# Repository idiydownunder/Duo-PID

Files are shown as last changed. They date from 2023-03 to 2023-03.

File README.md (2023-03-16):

# Duo-PID

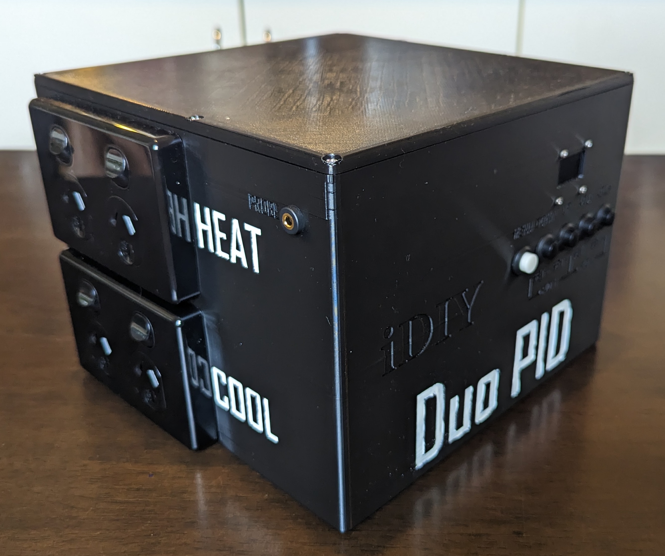
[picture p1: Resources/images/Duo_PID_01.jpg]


### Introduction

The Duo PID project is a device for controlling heating and or cooling operations with PID control. This project is split into two channels each with its own PID and temp sensor. I designed it for use with my fermentaion process when making home brew. However it could also be used for heating and cooling of spaces in the home or office. Other applications that come to mind are seed propergation, 3D Printer enclouser controll and even possibly food dehidrator or anything else that required accurate temp control.

**PLEASE NOTE:** *This is a mains powered project, attempt at your own risk.*

### Features

- 2 x Independate PID's
- Independate Tuning functions for each PID
- Adaptive Tuning Mode for each PID
- Independate on/off for each PID
- Heating, Cooling or Both modes
- Settings are saved to EPROM
- Auto Start mode in case of power loss
- Selectable C or F temp readouts

### PCB Gerber Files

Gerber files for PCB manufacture can be found in the Gerber folder.

- Pick the newest revision/version
- Visit https://jlcpcb.com/
- Sign In or Register
- Click 'Order Now'
- Click 'Add Gerber File'
- Select the Gerber .zip file
- Select build options. (I recommend leave defaults, but change qty, colour and select 'Specify a location' under 'Remove Order Number' option. Also make sure both 'SMT Assembly' and 'Stencil' options are off as they are not needed for this.)
- Once your happy with your selection, place order and pay.
- Wait for PCB's to arrive.

### PCB Schematic

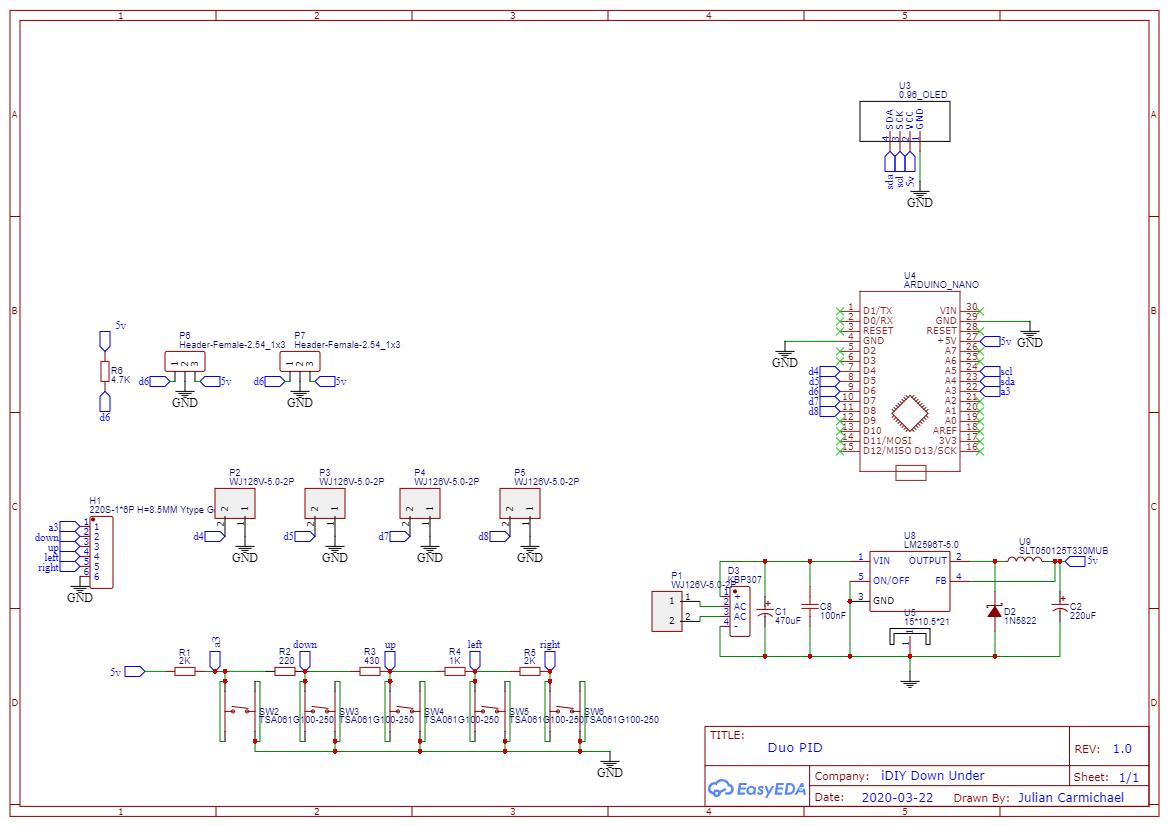
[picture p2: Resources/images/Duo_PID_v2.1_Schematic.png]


### BOM (Build of Materials)

Build of materials can be found the BOM folder. Most of the PCB components can be found in a .csv file, the rest you will need to source yourself from the .txt file. I would recommend places like Amazon, eBay and AliExpress.

- Find the .csv that matches the same revision as the Gerber file.
- Next visit https://lcsc.com/
- Sign In or Register
- Click on the 'BOM Tool' option.
- Now upload the .csv file.
- Set column with C##### numbers to LCSC Part Number.
- Click Next
- Adjust quantities to suit your needs. (Note some parts are optional and other have minimum order quantities)
- Once your happy with your selection, place order and pay.
- Wait for parts to arrive.

### STL Files

STL files are also included in the STL folder, So you can 3D Printer your own enslosure for this project. They are design to fit within the build plate of an Ender 3 (you may need to tweek the default setting to use the whole build plate).

My print/slicer setting for this was as follows;
- .4mm nozzel
- .2mm layer height
- 4 top and bottom layers
- 3 layer wall thickness
- 25% infill
- I printed with supports for the box shape areas and support blockers for the rounded areas.

### Duo_PID_Code_v1.0.ino

The compiled code is fairly large and as a result requires 29010 bytes of storage, for this reason an Arduino with a Mega 328P chipset is required. The code as makes use of a number of libaries that are required to be installed in your Arduino IDE first. Some are built in libaries that do not require installation, others can be found through the libary manager and others will need to be installed manually.

**Required Libaries** The EEPROM.h and Wire.h libaries are included with the Arduino IDE and should not need to be installed.

The OneWire.h and DallasTemperature.h can be easily installed throught the 'Libary Manager' as shown here;<br>
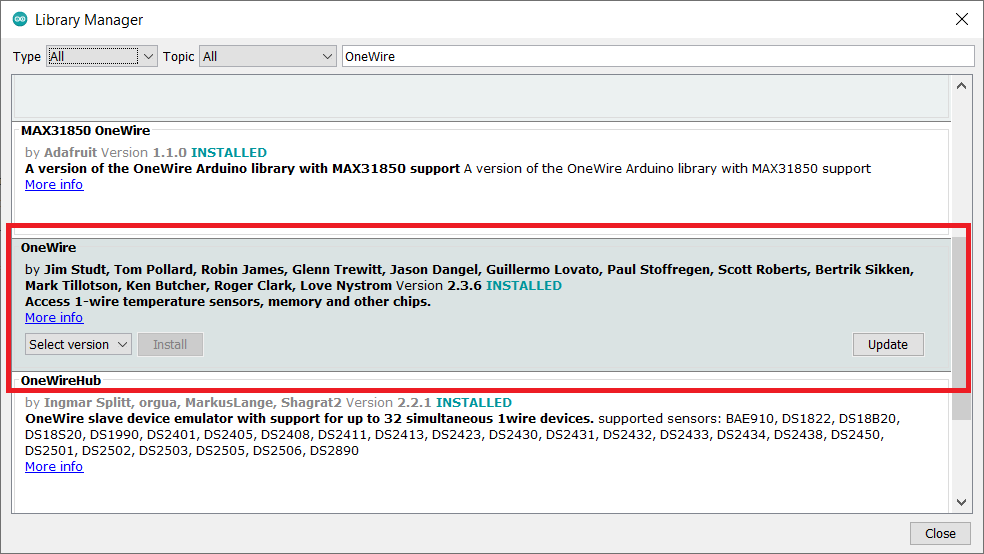
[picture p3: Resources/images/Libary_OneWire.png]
<br>
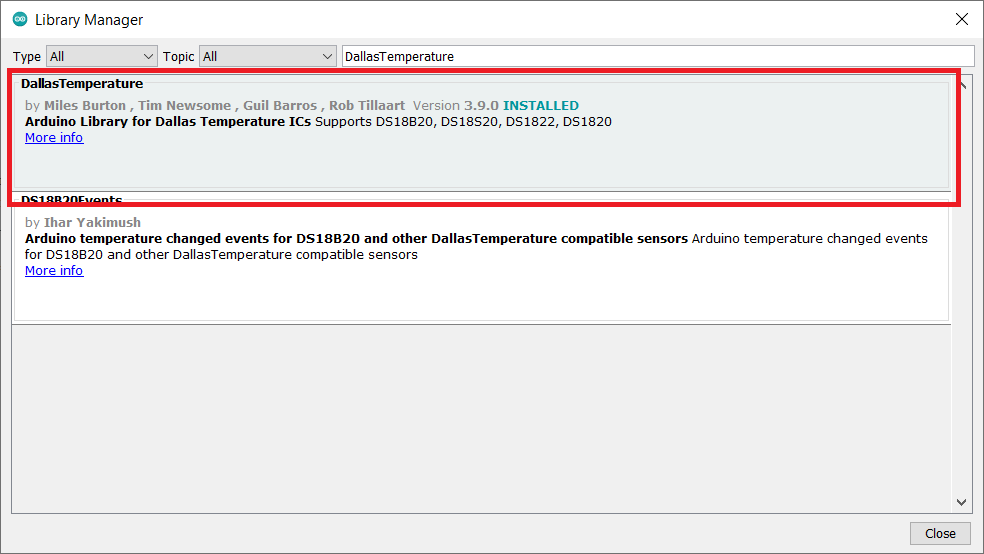
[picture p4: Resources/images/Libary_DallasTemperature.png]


The remaining two libaries (ssd1306.h and PID_V1.h) need to be installed manually, the best way to do this is to goto 'Sketch' >> 'Include Libary' >> 'Add .ZIP Libary...'<br>
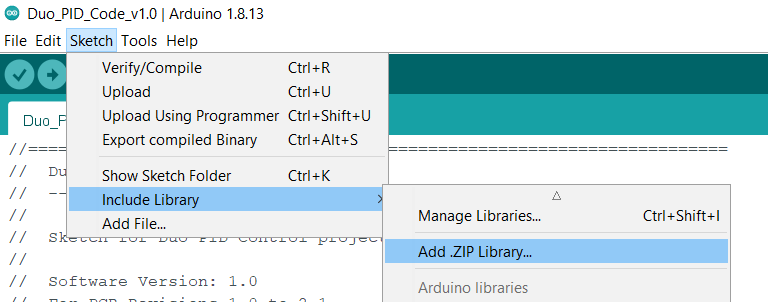
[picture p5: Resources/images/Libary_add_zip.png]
<br>
Both of these libary zip's can be found in the Resources/libaries folder within this repository or you can use the links below to view thier GitHub repos if you wish to download them from there;
- [ssd1306.h](https://github.com/lexus2k/ssd1306)
- [PID_v1.h](https://github.com/br3ttb/Arduino-PID-Library)

### Donate

While developing things like this are a passion and hobby for me. I ask that if you have found this educational, helpful or insiteful, maybe you could consider making a donation to the project. To help fund future development costs, mainly my time, coffee and supplies.

Cash donations can be made through my [PayPal.Me](https://www.paypal.com/paypalme/carmichaeljuian) link.

Crypto donations can be made to the following wallets;<br>
Bitcoin (BTC): 1Kt78m7LPZkkfxyMx8rVcdJxBftZw937Sc<br>
Monero (XMR): 4BAco3fES2cXfymfx7NVd62Z6EfgXNvaZg3tba8jWjvHR52cHDbmkiT5iEm3Kxq4XhbCeFEacCJzkBYtHpXwwGbJ2d7FWwr<br>

<br />This work is licensed under a <a rel="license" href="http://creativecommons.org/licenses/by-nc-sa/4.0/">Creative Commons Attribution-NonCommercial-ShareAlike 4.0 International License</a>.

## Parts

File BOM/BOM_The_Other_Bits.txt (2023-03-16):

5 x 12mm NO Non Latching Push Button Switchs
M4 Nuts and Bolts
M3 Nuts and Bolts
M2 Nuts and Bolts
1 x Arduino Nano (Mega 328P)
1 x OLED 0.96 Display
4 x GPO's (aka Power Points)
4 x SSR-40 DA-H with Heat Sinks
2 x DS18B20 Temp Probe
1 x Mains Transformer with output between 6-30v AC at 1A

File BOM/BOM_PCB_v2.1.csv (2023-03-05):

LCSC Part Number | Manufacture Part Number | Manufacturer | Package | Customer # | Description | RoHS | Order Qty. | Min\Mult Order Qty. | Unit Price | Order Price | Product Link
C155540 | EGH1EM221F12OTGOSO | AISHI(Aihua Group) | Plugin,D8xL12mm |  | 220uF 25V 8mm 12mm 460mΩ@100kHz 3.5mm ±20% 210mA@100kHz 7000hrs@105℃ Plugin,D8xL12mm Aluminum Electrolytic Capacitors - Leaded ROHS | yes | 10 | 10 | 0.0462 | 0.46 | https://assets.lcsc.com/images/lcsc/96x96/20230110_AISHI-Aihua-Group-EGH1EM221F12OTGOSO_C155540_front.jpg
C409821 | 05B104K500PF3C1N0R | STE(Songtian Elec) | Plugin,P=5.08mm |  | ±10% 50V 100nF X7R Plugin,P=5.08mm Multilayer Ceramic Capacitors MLCC - Leaded ROHS | yes | 10 | 10 | 0.0390 | 0.39 | https://assets.lcsc.com/images/lcsc/96x96/20230115_STE-Songtian-Elec-05B104K500PF3C1N0R_C409821_front.jpg
C4649 | C4649 | XSD | - |  | - Heat Sinks ROHS | yes | 5 | 5 | 0.0835 | 0.42 | https://assets.lcsc.com/images/lcsc/96x96/20221228_XSD-C4649_C4649_front.jpg
C2476 | 1N5822 | MDD（Microdiode Electronics） | DO-201AD |  | 40V 525mV@3A 3A DO-201AD Schottky Barrier Diodes (SBD) ROHS | yes | 5 | 5 | 0.0940 | 0.47 | https://assets.lcsc.com/images/lcsc/96x96/20190621_MDD-Microdiode-Electronics--1N5822_C2476_front.jpg
C127220 | MF1/4W-220Ω±1% T | CCO(Chian Chia Elec) | Plugin |  | Metal Film Resistors 220Ω 250V 250mW ±100ppm/℃ ±1% -55℃~+155℃ Plugin Through Hole Resistors ROHS | yes | 50 | 50 | 0.0106 | 0.53 | https://assets.lcsc.com/images/lcsc/96x96/20230102_CCO-Chian-Chia-Elec-MF1-4W-220R-1--T_C127220_front.jpg
C8404 | WJ126V-5.0-2P | Ningbo Kangnex Elec | Plugin,P=5mm |  | 18A -40℃~+105℃ 250V Green 14~26 Straight pin 5mm 2.5 1 2 Plugin,P=5mm Screw terminal ROHS | yes | 5 | 5 | 0.0739 | 0.37 | https://assets.lcsc.com/images/lcsc/96x96/20200709_Ningbo-Kangnex-Elec-WJ126V-5-0-2P_C8404_front.jpg
C34642 | KM477M050G20RR0VH2FP0 | CX(Dongguan Chengxing Elec) | Plugin,D10xL20mm |  | 470uF 50V 10mm 20mm 5mm ±20% 2000hrs@105℃ Plugin,D10xL20mm Aluminum Electrolytic Capacitors - Leaded ROHS | yes | 5 | 5 | 0.0898 | 0.45 | https://assets.lcsc.com/images/lcsc/96x96/20180914_CX-Dongguan-Chengxing-Elec-KM477M050G20RR0VH2FP0_C34642_front_10.jpg
C119339 | MF1/4W-4.7KΩ±1% T | CCO(Chian Chia Elec) | Plugin |  | Metal Film Resistors 4.7kΩ 250V 250mW ±100ppm/℃ ±1% -55℃~+155℃ Plugin Through Hole Resistors ROHS | yes | 50 | 50 | 0.0109 | 0.55 | https://assets.lcsc.com/images/lcsc/96x96/20230101_CCO-Chian-Chia-Elec-MF1-4W-4-7KR-1--T_C119339_front.jpg
C20648 | KBP307 | MDD（Microdiode Electronics） | KBP |  | 80A 1V@3A 10uA@600V 3A 600V -55℃~+150℃@(Tj) KBP Bridge Rectifiers ROHS | yes | 5 | 5 | 0.0888 | 0.44 | https://assets.lcsc.com/images/lcsc/96x96/20221229_MDD-Microdiode-Electronics--KBP307_C20648_front.jpg
C119324 | MF1/4W-1KΩ±1% T | CCO(Chian Chia Elec) | Plugin |  | Metal Film Resistors 1kΩ 250V 250mW ±100ppm/℃ ±1% -55℃~+155℃ Plugin Through Hole Resistors ROHS | yes | 50 | 50 | 0.0102 | 0.51 | https://assets.lcsc.com/images/lcsc/96x96/20230101_CCO-Chian-Chia-Elec-MF1-4W-1KR-1--T_C119324_front.jpg
C146243 | C146243 | BOOMELE(Boom Precision Elec) | Plugin,P=2.54mm |  | 2.54mm 单排 Gold Straight 3 Plugin,P=2.54mm Female Headers ROHS | yes | 10 | 10 | 0.0549 | 0.55 | https://assets.lcsc.com/images/lcsc/96x96/20180914_BOOMELE-Boom-Precision-Elec-C146243_C146243_front.jpg
C119330 | MF1/4W-2KΩ±1% T | CCO(Chian Chia Elec) | Plugin,2.3x6.5mm |  | Metal Film Resistors 2kΩ 250V 250mW ±100ppm/℃ ±1% -55℃~+155℃ Plugin,2.3x6.5mm Through Hole Resistors ROHS | yes | 50 | 50 | 0.0100 | 0.50 | https://assets.lcsc.com/images/lcsc/96x96/20230101_CCO-Chian-Chia-Elec-MF1-4W-2KR-1--T_C119330_front.jpg
C126046 | LM2596T-5.0 | HTC Korea TAEJIN Tech | TO-220-5 |  | Step-down type TO-220-5 DC-DC Converters ROHS | yes | 1 | 1 | 1.3014 | 1.30 | https://assets.lcsc.com/images/lcsc/96x96/20230102_HTC-Korea-TAEJIN-Tech-LM2596T-5-0_C126046_front.jpg
C326011 | SLT050125T330MUB | Sunltech Tech | Plugin |  | 4A 33uH Magnetic ring inductance ±20% 32mΩ Plugin Color Ring Inductors/Through Hole Inductors ROHS | yes | 5 | 5 | 0.2689 | 1.34 | https://assets.lcsc.com/images/lcsc/96x96/20181109_Sunltech-Tech-SLT050125T330MUB_C326011_front.jpg
C294506 | TSA061G100-250 | BRIGHT | Plugin |  | No NO PCPin 50mA 6.1mm 100MΩ 50000 250gf@±50gf 12V -25℃~+70℃ 6.1mm 10mm Black Round Button Straight SPST Plugin Tactile Switches ROHS | yes | 20 | 20 | 0.0228 | 0.46 | https://assets.lcsc.com/images/lcsc/96x96/20181005_BRIGHT-TSA061G100-250_C294506_front.jpg
C124415 | B-2200S06P-A120 | Ckmtw(Shenzhen Cankemeng) | Plugin,P=2.54mm |  | 2.54mm 单排 Brass Straight 1x6P 6 Plugin,P=2.54mm Female Headers ROHS | yes | 5 | 5 | 0.1116 | 0.56 | https://assets.lcsc.com/images/lcsc/96x96/20230101_Ckmtw-Shenzhen-Cankemeng-B-2200S06P-A120_C124415_front.jpg
C278329 | SDDJE30700 | ALPSALPINE | Plugin |  | Black Concave edge bending Double pole single throw O - Solder Lug(Straight foot) 10A 250V Plugin Rocker Switches ROHS | yes | 1 | 1 | 1.4462 | 1.45 | https://assets.lcsc.com/images/lcsc/96x96/20180918_ALPSALPINE-SDDJE30700_C278329_front.jpg
C124408 | B-2200S15P-A120 | Ckmtw(Shenzhen Cankemeng) | Plugin,P=2.54mm |  | 2.54mm 单排 Brass Straight 1x15P 15 Plugin,P=2.54mm Female Headers ROHS | yes | 5 | 5 | 0.2089 | 1.04 | https://assets.lcsc.com/images/lcsc/96x96/20230101_Ckmtw-Shenzhen-Cankemeng-B-2200S15P-A120_C124408_front.jpg
C119316 | MF1/4W-430Ω±1% T | CCO(Chian Chia Elec) | Plugin,2.3x6.5mm |  | Metal Film Resistors 430Ω 250V 250mW ±100ppm/℃ ±1% -55℃~+155℃ Plugin,2.3x6.5mm Through Hole Resistors ROHS | yes | 50 | 50 | 0.0073 | 0.37 | https://assets.lcsc.com/images/lcsc/96x96/20230101_CCO-Chian-Chia-Elec-MF1-4W-430R-1--T_C119316_front.jpg

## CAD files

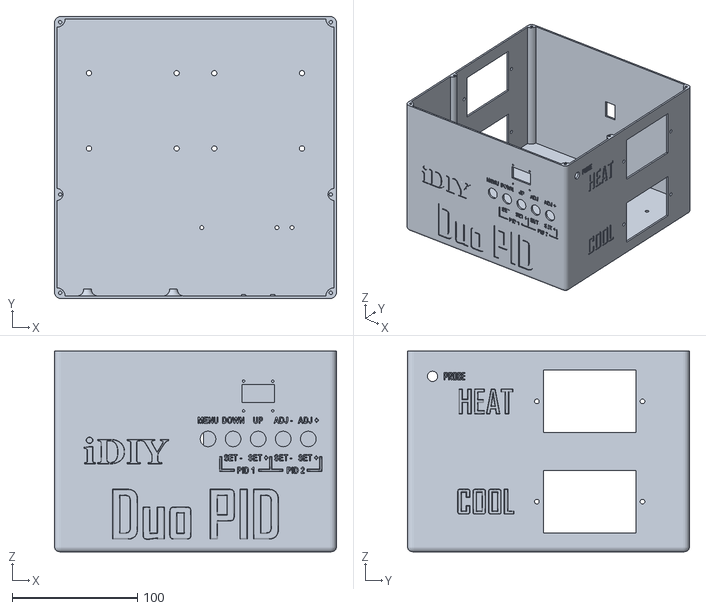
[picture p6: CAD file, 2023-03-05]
STL/Enclosure.stl
225.0 x 225.0 x 160.0

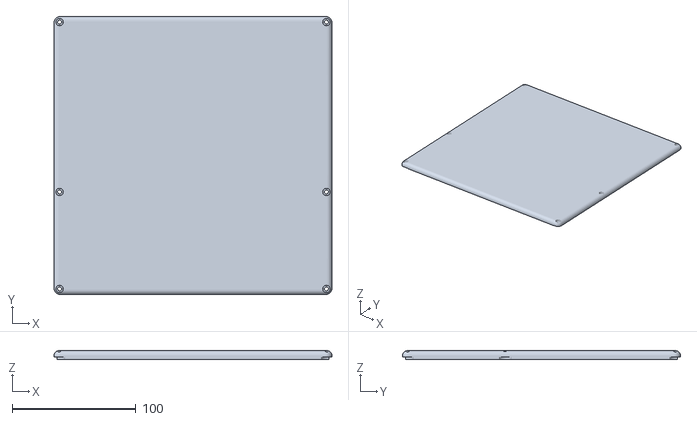
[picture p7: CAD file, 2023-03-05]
STL/Lid.stl
225.0 x 225.0 x 7.00

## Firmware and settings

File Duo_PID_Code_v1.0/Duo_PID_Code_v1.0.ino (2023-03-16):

//======================================================================
//  Duo PID Control
//  ---------------
//
//  Sketch for Duo PID Control project.
//
//  Software Version: 1.0 
//  For PCB Revisions 1.0 to 2.1
//
//  Copyright (c) 2023 iDIY Down Under
//  Author: Julian Carmichael (aka Digital Jester)
//
//  GitHub: https://github.com/idiydownunder/Duo-PID
//
//  This work is licensed under a Creative Commons 
//  Attribution-NonCommercial-ShareAlike 4.0 International License
//  http://creativecommons.org/licenses/by-nc-sa/4.0/
//
//======================================================================

//===================================
// Include Libarys
//===================================
#include <EEPROM.h>
#include <Wire.h>
#include "ssd1306.h"
#include "ssd1306_console.h"
#include <OneWire.h>
#include <DallasTemperature.h>
#include <PID_v1.h>
//=================================== 
// Define Button Constants
//===================================
#define btnRIGHT  5
#define btnLEFT   4
#define btnUP     3
#define btnDOWN   2
#define btnSELECT 1
#define btnNONE   0
#define BUTTON_DEBOUNCE 500     // button debounce value
//===================================
// Define Pins
//===================================
#define BUTTON_PIN A3       // Button Array
#define HEAT_1_PIN 4        // PID 1 Heating SSR Pin
#define COOL_1_PIN 5        // PID 1 Cooling SSR Pin
#define ONE_WIRE_BUS_PIN 6  // Temperature Sensor Pin
#define COOL_2_PIN 7        // PID 2 Heating SSR Pin
#define HEAT_2_PIN 8        // PID 2 Cooling SSR Pin
//=================================== 
// Define DS18B20 Constants
//===================================
#define TEMPERATURE_PRECISION 12  // Values 9, 10, 11 and 12 bit
#define tempMax 120               // Sensor MAX value = +125
#define tempMin -50               // Sensor MIN value = -55
//=================================== 
// Define Display Constants
//===================================
#define main 0
#define pid1s 1
#define pid1t 2
#define pid2s 3
#define pid2t 4
#define pidg 5
#define pidtn 6
#define set 7
//=================================== 
// Define Default Constants
//===================================
#define defSetpoint 26.0
#define defKp 5.0
#define defKi 2.5
#define defKd 5.0

const unsigned char PROGMEM idiylogo[] = {
0x00, 0x00, 0x00, 0x1C, 0x3E, 0xFE, 0x3E, 0x3E, 0x3E, 0x1C, 0x10, 0xE0, 0x00, 0x02, 0x02, 0x12,
0x0E, 0xFE, 0xFE, 0xFE, 0xFE, 0xFE, 0xFE, 0xFE, 0xFE, 0x02, 0xE2, 0x06, 0x06, 0x1E, 0xFC, 0xFC,
0xFC, 0xFC, 0xF8, 0xF0, 0xE0, 0xC0, 0x00, 0x00, 0x00, 0x00, 0x02, 0x02, 0x06, 0xFE, 0xFE, 0xFE,
0xFE, 0xFE, 0xFE, 0xFE, 0xFE, 0x02, 0xC2, 0x02, 0x02, 0x02, 0x06, 0x0E, 0x1E, 0x3E, 0xFE, 0xFE,
0xFE, 0xFE, 0xFE, 0xFE, 0xF2, 0xC2, 0x82, 0x00, 0x10, 0x00, 0x82, 0xC2, 0x72, 0x1E, 0x86, 0x86,
0x02, 0x02, 0x00, 0x10, 0x00, 0x00, 0x01, 0x01, 0xFF, 0xFF, 0xFF, 0xFF, 0xFF, 0xFF, 0xFF, 0x00,
0x00, 0x00, 0x00, 0x00, 0x00, 0x00, 0xFF, 0xFF, 0xFF, 0xFF, 0xFF, 0xFF, 0xFF, 0xFF, 0x00, 0xFF,
0x00, 0x00, 0x00, 0xC1, 0xFF, 0xFF, 0xFF, 0xFF, 0xFF, 0xFF, 0xFF, 0xFF, 0x00, 0x18, 0x00, 0x00,
0x00, 0x00, 0xFF, 0xFF, 0xFF, 0xFF, 0xFF, 0xFF, 0xFF, 0xFF, 0x00, 0xFF, 0x00, 0x00, 0x00, 0x00,
0x00, 0x00, 0x00, 0x00, 0x03, 0x07, 0x1F, 0xFF, 0xFF, 0xFF, 0xFF, 0xFF, 0xFE, 0xFC, 0xFE, 0x03,
0xF0, 0x1C, 0x06, 0x03, 0x00, 0x00, 0x00, 0x00, 0x00, 0x00, 0x00, 0x20, 0x20, 0x3F, 0x3F, 0xFF,
0x3F, 0x3F, 0x3F, 0x3F, 0x20, 0xA0, 0x00, 0x20, 0x20, 0x20, 0x38, 0x3F, 0xFF, 0x3F, 0x3F, 0x3F,
0x3F, 0x3F, 0x3F, 0x20, 0xEF, 0x20, 0x30, 0x3C, 0xBF, 0x7F, 0x1F, 0x1F, 0x1F, 0x0F, 0x87, 0x43,
0x01, 0x10, 0x0E, 0x00, 0x20, 0x20, 0x30, 0x3F, 0xBF, 0x7F, 0x3F, 0x3F, 0x3F, 0x3F, 0x3F, 0x20,
0x6F, 0x20, 0x00, 0x00, 0x00, 0x00, 0x00, 0x00, 0x20, 0x20, 0x20, 0x30, 0x3F, 0xBF, 0x3F, 0x3F,
0x3F, 0x3F, 0x3F, 0x3F, 0x20, 0x6F, 0x20, 0x00, 0x00, 0x00, 0x00, 0x00, 0x00, 0x00, 0x00, 0x00,
0x00, 0x00, 0x01, 0x00, 0x00, 0x00, 0x00, 0x00, 0x00, 0x00, 0x00, 0x00, 0x01, 0x00, 0x01, 0x00,
0x30, 0x78, 0x30, 0x40, 
};

int displayState=main;     // enumerated variable that holds state for display state

unsigned long last_press;     // Hold Last Button Press, Used to Debounce User Input
double temp_buffer = 1.5;     // Holds the buffer value for PID heat/cool swing
double temp_inc = 0.5;        // Holds stepper value for Temp incress/decress
double pidGAT = 10;           // Holds value for Adaptive Tuning GAP
bool pid1HeatOnly = true;     // Used to hold the PID in heat only mode
bool pid1CoolOnly = false;    // Used to hold the PID in cool only mode
bool pid1AddTune=false;       // Used to toggle Adaptive Tuning mode
bool pid1PonE=false;          // PID P calculation method
bool pid1AS=true;             // Used to auto start PID at start up
bool pid2HeatOnly = true;     // Used to hold the PID in heat only mode
bool pid2CoolOnly = false;    // Used to hold the PID in cool only mode
bool pid2AddTune=false;       // Used to toggle Adaptive Tuning mode
bool pid2PonE=false;          // PID P calculation method
bool pid2AS=true;             // Used to auto start PID at start up
bool showTuneNote = true;     // Toggle Tuning Notes on/off
bool showPIDTune=true;        // Toggle PID tuning on/off
bool showValPer=false;        // Display output as value or percent
bool isF = false;             // Used to display Fahrenheit temps
int placeMarker = 1;          // Used to mark setting options
int placeMax = 0;             // Used to define how many options are in menu
int senCount=0;               // Used to hold the number of temp sensors found at start up

//PID Relay variables
int WindowSize = 5000;        // Used to define PID Timing Window
unsigned long windowStartTimeTun1;  // Holds PID current timing
unsigned long windowStartTimeTun2;  // Holds PID current timing

//Define Variables we'll be connecting to for PID control
double pid1_Setpoint, pid1_Input, pid1_Output;
double pid2_Setpoint, pid2_Input, pid2_Output;

//Specify the links and initial tuning parameters
double pid1_Kp=1.2, pid1_Ki=0.2, pid1_Kd=0.5;
double pid2_Kp=1.2, pid2_Ki=0.2, pid2_Kd=0.5;
double pid1_a_Kp=2, pid1_a_Ki=0.5, pid1_a_Kd=2;
double pid2_a_Kp=2, pid2_a_Ki=0.5, pid2_a_Kd=2;

// Setup PID's
PID PID_1(&pid1_Input, &pid1_Output, &pid1_Setpoint, pid1_Kp, pid1_Ki, pid1_Kd, P_ON_M, DIRECT);
PID PID_2(&pid2_Input, &pid2_Output, &pid2_Setpoint, pid2_Kp, pid2_Ki, pid2_Kd, P_ON_M, DIRECT);

// Setup a oneWire instance to communicate with any OneWire devices (not just Maxim/Dallas temperature ICs)
OneWire oneWire(ONE_WIRE_BUS_PIN);

DallasTemperature sensors(&oneWire);    // Pass our oneWire reference to Dallas Temperature. 
DeviceAddress PID_1_TEMP, PID_2_TEMP;   // arrays to hold device addresses

// setup OLED display
Ssd1306Console  display;

//------------------------------------------------------------------------------------------------------
// SETUP
//------------------------------------------------------------------------------------------------------
void setup() {
  
  ssd1306_128x64_i2c_init();  // start oled display

  sensors.begin();            //start temp sensors

  int y = 0;
  int inc =8;
  int del = 500;
  
  ssd1306_clearScreen();
  ssd1306_setFixedFont(ssd1306xled_font6x8);
  display.setCursor(0,0); 
  display.print(F("Loading Settings..."));
  LOAD_SETTINGS();  // Load Settings
  delay(del);

  y+=inc;
  display.setCursor(0,y);
  display.print(F("Checking Settings..."));
  CHK_SETTINGS(); // Check Run Time Settings
  delay(del);
  ssd1306_clearScreen();
  y=0;
  display.setCursor(0,y);
  display.print(F("Locating devices..."));
  delay(del);
  
  y+=inc;
  display.setCursor(0,y);
  display.print(F("Found "));
  senCount=sensors.getDeviceCount();
  display.print(senCount);
  display.print(F(" devices."));
  delay(del);
  
  y+=inc;
  display.setCursor(0,y);
  if (!sensors.getAddress(PID_1_TEMP, 0)) {display.print(F("FAIL: PID_1_TEMP"));y+=inc;display.setCursor(0,y);delay(1200);}
  if (!sensors.getAddress(PID_2_TEMP, 1)) {display.print(F("FAIL: PID_2_TEMP"));y+=inc;display.setCursor(0,y);delay(1200);}
  delay(del);

  y+=inc;
  display.setCursor(0,y);
  display.print(F("Set device Percision"));
  sensors.setResolution(PID_1_TEMP, TEMPERATURE_PRECISION);
  sensors.setResolution(PID_2_TEMP, TEMPERATURE_PRECISION);
  delay(del);
  
  ssd1306_clearScreen();
  y=0;
  display.setCursor(0,y);
  display.print(F("Set I/O Pin Operation"));
  pinMode(HEAT_1_PIN,OUTPUT);
  pinMode(HEAT_2_PIN,OUTPUT);
  pinMode(COOL_1_PIN,OUTPUT);
  pinMode(COOL_2_PIN,OUTPUT);
  delay(del);

  y+=inc;
  display.setCursor(0,y);
  display.print(F("Set Time Markers."));
  windowStartTimeTun1 = millis();
  windowStartTimeTun2 = millis();
  last_press=millis();
  delay(del);
  
  ssd1306_clearScreen();
  y=0;
  display.setCursor(0,y);
  display.print(F("Set PID Limits."));
  setPIDLimit();
  delay(del);

  y+=inc;
  display.setCursor(0,y);
  display.print(F("Set PID Tuning."));
  setPIDTuning();
  delay(del);

  y+=inc;
  display.setCursor(0,y);
  display.print(F("Run PID Auto Start."));
  //turn the PID's on
  if(pid1AS){if(senCount>=1){PID_1.SetMode(AUTOMATIC);}}
  if(pid2AS){if(senCount>=2){PID_2.SetMode(AUTOMATIC);}}
  delay(del);
  
  ssd1306_clearScreen();
  ssd1306_printFixed(10,  35, "DUO PID", STYLE_BOLD);
  ssd1306_printFixed(19, 45, "CONTROL", STYLE_BOLD);
  ssd1306_printFixed(32, 52, "Version: 1.0", STYLE_ITALIC);
  ssd1306_drawBitmap(43, 32, 85, 26, idiylogo);
  delay(3000);
  
  ssd1306_clearScreen();

  displayState=main;
  
}
//------------------------------------------------------------------------------------------------------
// MAIN LOOP
//------------------------------------------------------------------------------------------------------
void loop() {

  sensors.requestTemperatures(); // Send the command to get temperatures

  runPID(); // Run the PID's  

  // Handel User Input
  if ((millis()-last_press) > BUTTON_DEBOUNCE){
    button_handler();               
  }

  oledDisplay(); // Update Display
  
}
//------------------------------------------------------------------------------------------------------
// This routine is used to run and control how the PID's behave.
//------------------------------------------------------------------------------------------------------
void runPID(){

  // Check to see there is an input for PID
  if(senCount>=1){
    pid1_Input = sensors.getTempC(PID_1_TEMP);      // Update PID input temperature
    if(pid1_Input==-127.00){PID_1.SetMode(MANUAL);} // Something went wrong turn off PID
  }else{
    pid1_Input = -127.00;
    PID_1.SetMode(MANUAL);  // Something went wrong turn off PID
  }

  if (PID_1.GetMode()==AUTOMATIC){  // See if PID is on or off    
    if (pid1_Input>=pid1_Setpoint+temp_buffer){
      if(!pid1HeatOnly){
        PID_1.SetControllerDirection(REVERSE);
        digitalWrite(HEAT_1_PIN, LOW);
      }else{
        PID_1.SetControllerDirection(DIRECT);
        digitalWrite(COOL_1_PIN, LOW);
      }
    }else if (pid1_Input<=pid1_Setpoint-temp_buffer){
      if(!pid1CoolOnly){
        PID_1.SetControllerDirection(DIRECT);
        digitalWrite(COOL_1_PIN, LOW);
      }else{
        PID_1.SetControllerDirection(REVERSE);
        digitalWrite(HEAT_1_PIN, LOW);
      }
    }

    if(pid1AddTune){ // Is Adapive tuning mode being used
      if(abs(pid1_Setpoint-pid1_Input)<=pidGAT){
        if(pid1PonE){
          PID_1.SetTunings(pid1_Kp, pid1_Ki, pid1_Kd,P_ON_E);
        }else{
          PID_1.SetTunings(pid1_Kp, pid1_Ki, pid1_Kd,P_ON_M);
        }
      }else{
        if(pid1PonE){
          PID_1.SetTunings(pid1_a_Kp, pid1_a_Ki, pid1_a_Kd,P_ON_E);
        }else{
          PID_1.SetTunings(pid1_a_Kp, pid1_a_Ki, pid1_a_Kd,P_ON_M);
        }
      }
    }
  
    PID_1.Compute(); // Run PID calcutaions

    // Track PID on/off timing
    if (millis() - windowStartTimeTun1 > WindowSize){ 
      windowStartTimeTun1 = millis();
    }

    // Update PID outputs
    if (PID_1.GetDirection()==DIRECT){
      if (pid1_Output > millis() - windowStartTimeTun1){
        digitalWrite(HEAT_1_PIN, HIGH);
      } else {
        digitalWrite(HEAT_1_PIN, LOW);
      }
    }
    if (PID_1.GetDirection()==REVERSE){
      if (pid1_Output > millis() - windowStartTimeTun1){
        digitalWrite(COOL_1_PIN, HIGH);
      } else {
        digitalWrite(COOL_1_PIN, LOW);
      }
    }
  }else{
    // Make sure PID outputs are off
    pid1_Output=0;
    digitalWrite(HEAT_1_PIN, LOW);
    digitalWrite(COOL_1_PIN, LOW);
  }

  if(senCount>=2){
    pid2_Input = sensors.getTempC(PID_2_TEMP); // Update PID input temperature
    if(pid2_Input==-127.00){PID_2.SetMode(MANUAL);}
  }else{
    pid2_Input = -127.00;
    PID_2.SetMode(MANUAL);
  }

  if (PID_2.GetMode()==AUTOMATIC){
    if (pid2_Input>=pid2_Setpoint+temp_buffer){
      if(!pid2HeatOnly){
        PID_2.SetControllerDirection(REVERSE);
        digitalWrite(HEAT_2_PIN, LOW);
      }else{
        PID_2.SetControllerDirection(DIRECT);
        digitalWrite(COOL_2_PIN, LOW);
      }
    }else if (pid2_Input<=pid2_Setpoint-temp_buffer){
      if(!pid2CoolOnly){
        PID_2.SetControllerDirection(DIRECT);
        digitalWrite(COOL_2_PIN, LOW);
      }else{
        PID_2.SetControllerDirection(REVERSE);
        digitalWrite(HEAT_2_PIN, LOW);
      }
    }

    if(pid2AddTune){
      if(abs(pid2_Setpoint-pid2_Input)<=pidGAT){
        if(pid2PonE){
          PID_2.SetTunings(pid2_Kp, pid2_Ki, pid2_Kd,P_ON_E);
        }else{
          PID_2.SetTunings(pid2_Kp, pid2_Ki, pid2_Kd,P_ON_M);
        }
      }else{
        if(pid2PonE){
          PID_2.SetTunings(pid2_a_Kp, pid2_a_Ki, pid2_a_Kd,P_ON_E);
        }else{
          PID_2.SetTunings(pid2_a_Kp, pid2_a_Ki, pid2_a_Kd,P_ON_M);
        }
      }
    }
    
    PID_2.Compute();
  
    if (millis() - windowStartTimeTun2 > WindowSize){ 
      windowStartTimeTun2 = millis();
    }

    if (PID_2.GetDirection()==DIRECT){
      if (pid2_Output > millis() - windowStartTimeTun2){
        digitalWrite(HEAT_2_PIN, HIGH);
      } else {
        digitalWrite(HEAT_2_PIN, LOW);
      }
    }
    if (PID_2.GetDirection()==REVERSE){
      if (pid2_Output > millis() - windowStartTimeTun2){
        digitalWrite(COOL_2_PIN, HIGH);
      } else {
        digitalWrite(COOL_2_PIN, LOW);
      }
    }
  }else{
    pid2_Output=0;
    digitalWrite(HEAT_2_PIN, LOW);
    digitalWrite(COOL_2_PIN, LOW);
  }
}
//------------------------------------------------------------------------------------------------------
// This routine is used to set the PID tuning options.
//------------------------------------------------------------------------------------------------------
void setPIDTuning(){
  if(pid1PonE){
    PID_1.SetTunings(pid1_Kp, pid1_Ki, pid1_Kd,P_ON_E);
  }else{
    PID_1.SetTunings(pid1_Kp, pid1_Ki, pid1_Kd,P_ON_M);
  }
  if(pid2PonE){
    PID_2.SetTunings(pid2_Kp, pid2_Ki, pid2_Kd,P_ON_E);
  }else{
    PID_2.SetTunings(pid2_Kp, pid2_Ki, pid2_Kd,P_ON_M);
  }
}
//------------------------------------------------------------------------------------------------------
// This routine is used to set the PID output limits.
//------------------------------------------------------------------------------------------------------
void setPIDLimit(){
  PID_1.SetOutputLimits(0, WindowSize); //tell the PID to range between 0 and the full window size
  PID_2.SetOutputLimits(0, WindowSize); //tell the PID to range between 0 and the full window size
}
//------------------------------------------------------------------------------------------------------
// This routine is used to save settings.
//------------------------------------------------------------------------------------------------------
void SAVE_SETTINGS()
{
  EEPROM.put(0,isF);      
  EEPROM.put(1,pid1HeatOnly);
  EEPROM.put(2,pid1CoolOnly);
  EEPROM.put(3,pid1AddTune);
  EEPROM.put(4,pid1PonE);
  EEPROM.put(5,pid1AS);
  EEPROM.put(6,pid2HeatOnly);
  EEPROM.put(7,pid2CoolOnly);
  EEPROM.put(8,pid2AddTune);
  EEPROM.put(9,pid2PonE);
  EEPROM.put(10,pid2AS);
  EEPROM.put(11,showTuneNote);
  EEPROM.put(12,showPIDTune);
  EEPROM.put(13,showValPer);
  EEPROM.put(18,WindowSize);
  
  EEPROM.put(20,pidGAT);
  EEPROM.put(24,temp_buffer);
  EEPROM.put(28,temp_inc);
  EEPROM.put(32,pid1_Setpoint);
  EEPROM.put(36,pid1_Kp);
  EEPROM.put(40,pid1_Ki);
  EEPROM.put(44,pid1_Kd);
  EEPROM.put(48,pid1_a_Kp);
  EEPROM.put(52,pid1_a_Ki);
  EEPROM.put(56,pid1_a_Kd);
  //EEPROM.put(60,);
  EEPROM.put(64,pid2_Setpoint);
  EEPROM.put(68,pid2_Kp);
  EEPROM.put(72,pid2_Ki);
  EEPROM.put(76,pid2_Kd);
  EEPROM.put(80,pid2_a_Kp);
  EEPROM.put(84,pid2_a_Ki);
  EEPROM.put(88,pid2_a_Kd);
  //EEPROM.put(92,);
}
//------------------------------------------------------------------------------------------------------
// This routine is used to load settings.
//------------------------------------------------------------------------------------------------------
void LOAD_SETTINGS()
{
  EEPROM.get(0,isF);      
  EEPROM.get(1,pid1HeatOnly);
  EEPROM.get(2,pid1CoolOnly);
  EEPROM.get(3,pid1AddTune);
  EEPROM.get(4,pid1PonE);
  EEPROM.get(5,pid1AS);
  EEPROM.get(6,pid2HeatOnly);
  EEPROM.get(7,pid2CoolOnly);
  EEPROM.get(8,pid2AddTune);
  EEPROM.get(9,pid2PonE);
  EEPROM.get(10,pid2AS);
  EEPROM.get(11,showTuneNote);
  EEPROM.get(12,showPIDTune);
  EEPROM.get(13,showValPer);
  EEPROM.get(18,WindowSize);
  
  EEPROM.get(20,pidGAT);
  EEPROM.get(24,temp_buffer);
  EEPROM.get(28,temp_inc);
  EEPROM.get(32,pid1_Setpoint);
  EEPROM.get(36,pid1_Kp);
  EEPROM.get(40,pid1_Ki);
  EEPROM.get(44,pid1_Kd);
  EEPROM.get(48,pid1_a_Kp);
  EEPROM.get(52,pid1_a_Ki);
  EEPROM.get(56,pid1_a_Kd);
  //EEPROM.get(60,);
  EEPROM.get(64,pid2_Setpoint);
  EEPROM.get(68,pid2_Kp);
  EEPROM.get(72,pid2_Ki);
  EEPROM.get(76,pid2_Kd);
  EEPROM.get(80,pid2_a_Kp);
  EEPROM.get(84,pid2_a_Ki);
  EEPROM.get(88,pid2_a_Kd);
  //EEPROM.get(92,);
  
}
//------------------------------------------------------------------------------------------------------
// This routine is used to check settings for valid input or a default value is assigned.
//------------------------------------------------------------------------------------------------------
void CHK_SETTINGS(){
  if(isnan(pid1_Setpoint)){pid1_Setpoint=defSetpoint;}
  if(pid1_Setpoint<tempMin){pid1_Setpoint=defSetpoint;}
  if(pid1_Setpoint>tempMax){pid1_Setpoint=defSetpoint;}
  
  if(isnan(pid2_Setpoint)){pid2_Setpoint=defSetpoint;}
  if(pid2_Setpoint<tempMin){pid2_Setpoint=defSetpoint;}
  if(pid2_Setpoint>tempMax){pid2_Setpoint=defSetpoint;}
  
  if(isnan(pidGAT)){pidGAT=10;}
  if(pidGAT<1){pidGAT=1;}
  if(pidGAT>10){pidGAT=10;}
  
  if(isnan(pid1_Kp)){pid1_Kp=defKp;}
  if(pid1_Kp<0){pid1_Kp=defKp;}
  if(isnan(pid1_Ki)){pid1_Ki=defKi;}
  if(pid1_Ki<0){pid1_Ki=defKi;}
  if(isnan(pid1_Kd)){pid1_Kd=defKd;}
  if(pid1_Kd<0){pid1_Kd=defKd;}
  
  if(isnan(pid2_Kp)){pid2_Kp=defKp;}
  if(pid2_Kp<0){pid2_Kp=defKp;}
  if(isnan(pid2_Ki)){pid2_Ki=defKi;}
  if(pid2_Ki<0){pid2_Ki=defKi;}
  if(isnan(pid2_Kd)){pid2_Kd=defKd;}
  if(pid2_Kd<0){pid2_Kd=defKd;}
  
  if(isnan(pid1_a_Kp)){pid1_a_Kp=4.0;}
  if(pid1_a_Kp<0){pid1_a_Kp=4.0;}
  if(isnan(pid1_a_Ki)){pid1_a_Ki=2.0;}
  if(pid1_a_Ki<0){pid1_a_Ki=2.0;}
  if(isnan(pid1_a_Kd)){pid1_a_Kd=5.0;}
  if(pid1_a_Kd<0){pid1_a_Kd=5.0;}
  
  if(isnan(pid2_a_Kp)){pid2_a_Kp=4.0;}
  if(pid2_a_Kp<0){pid2_a_Kp=4.0;}
  if(isnan(pid2_a_Ki)){pid2_a_Ki=2.0;}
  if(pid2_a_Ki<0){pid2_a_Ki=2.0;}
  if(isnan(pid2_a_Kd)){pid2_a_Kd=5.0;}
  if(pid2_a_Kd<0){pid2_a_Kd=5.0;}
  
  if(isnan(WindowSize)){WindowSize=5000;}
  if(WindowSize<1000){WindowSize=1000;}
  if(WindowSize>10000){WindowSize=10000;}
  
  if(isnan(temp_buffer)){temp_buffer=3.0;}
  if(temp_buffer<0){temp_buffer=1.0;}
  if(temp_buffer>10){temp_buffer=10.0;}
  
  if(isnan(temp_inc)){temp_inc=0.5;}
  if(temp_inc<0.01){temp_inc=0.01;}
  if(temp_inc>1){temp_inc=1;}
  
  if(isnan(pid1HeatOnly)){pid1HeatOnly=true;}
  if(pid1HeatOnly>1){pid1HeatOnly=true;}
  if(isnan(pid1CoolOnly)){pid1CoolOnly=false;}
  if(pid1CoolOnly>1){pid1CoolOnly=false;}
  if((pid1HeatOnly)&&(pid1CoolOnly)){pid1CoolOnly=false;}
  
  if(isnan(pid2HeatOnly)){pid2HeatOnly=true;}  
  if(pid2HeatOnly>1){pid2HeatOnly=true;}
  if(isnan(pid2CoolOnly)){pid2CoolOnly=false;}
  if(pid2CoolOnly>1){pid2CoolOnly=false;}
  if((pid2HeatOnly)&&(pid2CoolOnly)){pid2CoolOnly=false;}
  
  if(isnan(pid1AS)){pid1AS=false;}
  if(pid1AS>1){pid1AS=false;}
  
  if(isnan(pid2AS)){pid2AS=false;}
  if(pid2AS>1){pid2AS=false;}
  
  if(isnan(pid1AddTune)){pid1AddTune=false;}
  if(pid1AddTune>1){pid1AddTune=false;}
  
  if(isnan(pid2AddTune)){pid2AddTune=false;}
  if(pid2AddTune>1){pid2AddTune=false;}
  
  if(isnan(isF)){isF=false;}
  if(isF>1){isF=false;}
  
  if(isnan(showTuneNote)){showTuneNote=true;}
  if(showTuneNote>1){showTuneNote=true;}
  if(isnan(showPIDTune)){showPIDTune=true;}
  if(showPIDTune>1){showPIDTune=true;}
  if(isnan(showValPer)){showValPer=false;}
  if(showValPer>1){showValPer=false;}
}
//------------------------------------------------------------------------------------------------------
// This routine is used to display the temp on the oled.
//------------------------------------------------------------------------------------------------------
void displayTemp(double tmp){
  if(tmp==-127.00){
    display.print(F("ERROR"));
  }else{
    if (isF){
      display.print(DallasTemperature::toFahrenheit(tmp));
      display.print(F(" F"));
    }else{
      display.print(tmp);
      display.print(F(" C"));
    }
  }
}
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
